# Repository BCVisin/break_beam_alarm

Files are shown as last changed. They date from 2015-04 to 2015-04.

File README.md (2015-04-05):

# Break Beam Alarm

A dual laser break beam sensor system. 

###Details

I needed to set up an alarm system on 2 doors that lead out to the pool area so we will be notified if our children walked outside.  I didn't like the door alarm systems like this http://amzn.com/B0046786U4 since they don't work on the sliding door and the screen door. I wanted a system that checked to see if anyone crossed the door threshold.  A break beam system was in order. I thought the Pi would be a great at this and it would be a fun little project.

I am using the following hardware:
 1. Raspberry Pi A+ - The brains http://amzn.com/B00PEX05TO
 2. Edimax EW-7811Un 150Mbps 11n Wi-Fi USB Adapter - To connect the Pi to the network http://amzn.com/B003MTTJOY
 3. Kingston Digital 8 GB microSDHC - The Pi's memory http://amzn.com/B004S1PNE0
 4. Anker 10000mAh Battery Power Bank - In case of power outage to keep the system running http://amzn.com/B009USAJCC
 5. 2x Laser Diode - LASERS (need I say more?) https://www.adafruit.com/products/1054
 6. 2x Photo Cel (CdS photoresistor) - To detect the light changes when the laser beam is broken, https://www.adafruit.com/products/161
 7. 3x Square Buttons - Tactile reset buttons https://www.adafruit.com/products/1010
 8. USB Powered Speakers - To play various alarm sounds https://www.adafruit.com/products/1363
 9. MCP3008 - 8-Channel 10-Bit ADC - http://www.adafruit.com/products/856
 10. Various resistors for LEDs and the photo cel

###Requirements

 - A laser sensor across 2 door frame
 - 2 bypass buttons located on the upper part of the wall by the door so the kids can't reach it
 - When either beam is broken for the first time, it sounds an alarm and turns on an LED
 - When either beam is broken again (before being reset) it sounds a second (different) alarm and truns on a different LED
 - When either bypass button is pushed it will silense and reset the alarms
 - When either bypass button is pushed it will give a grace period (5 seconds?) to pass through the beams without alarms being triggered
 - Ability to run neither, one or the other, or both laser sensors at any give time

###Images
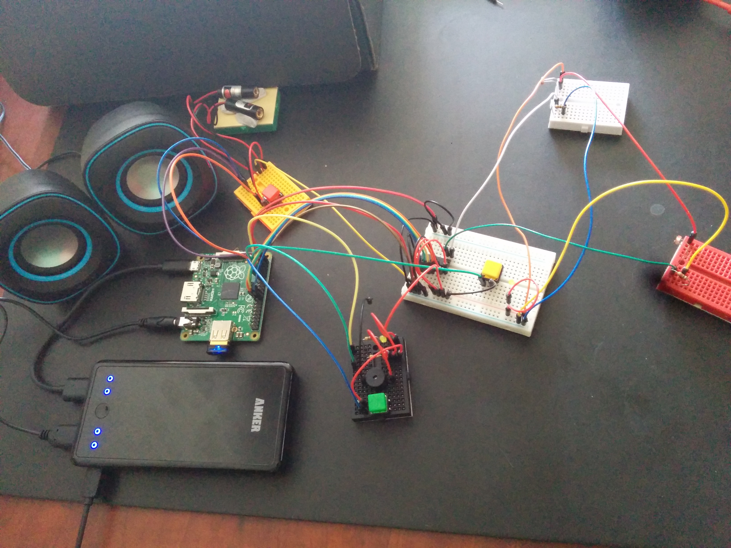
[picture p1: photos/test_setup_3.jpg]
Image of Test Setup

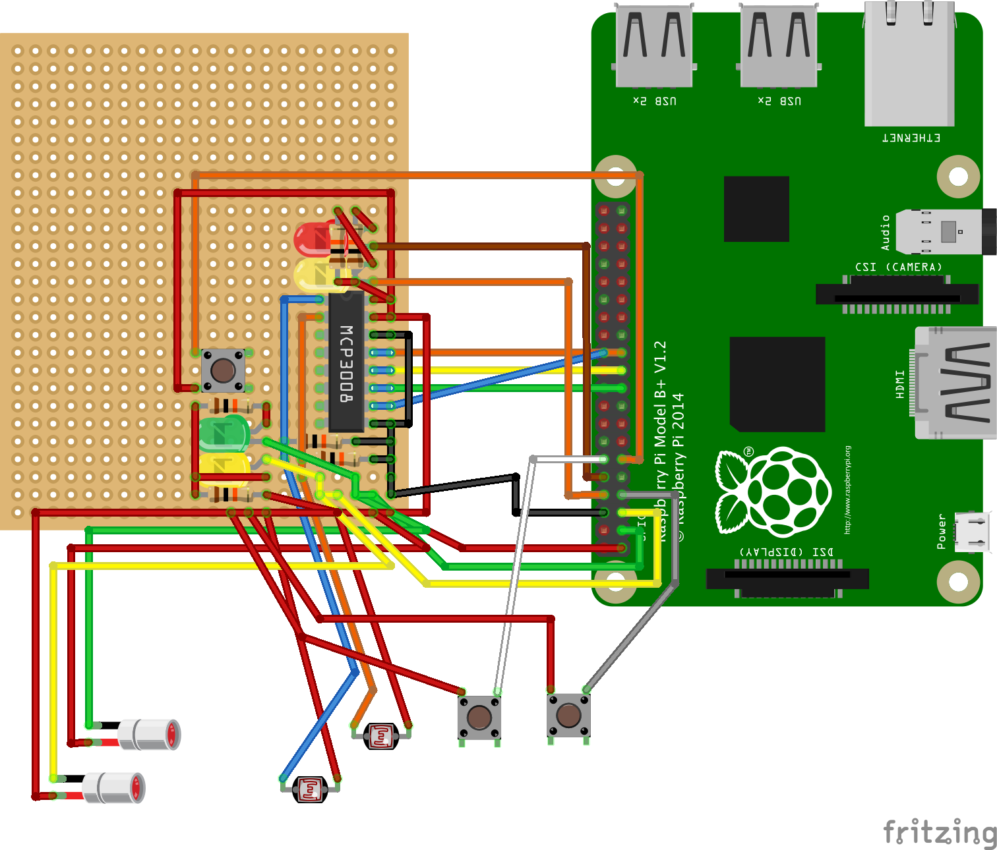
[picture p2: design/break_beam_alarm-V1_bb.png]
Image of Circuit


###Notes

The script MUST be ran as root since it needs access to the Pi's GPIO ports.

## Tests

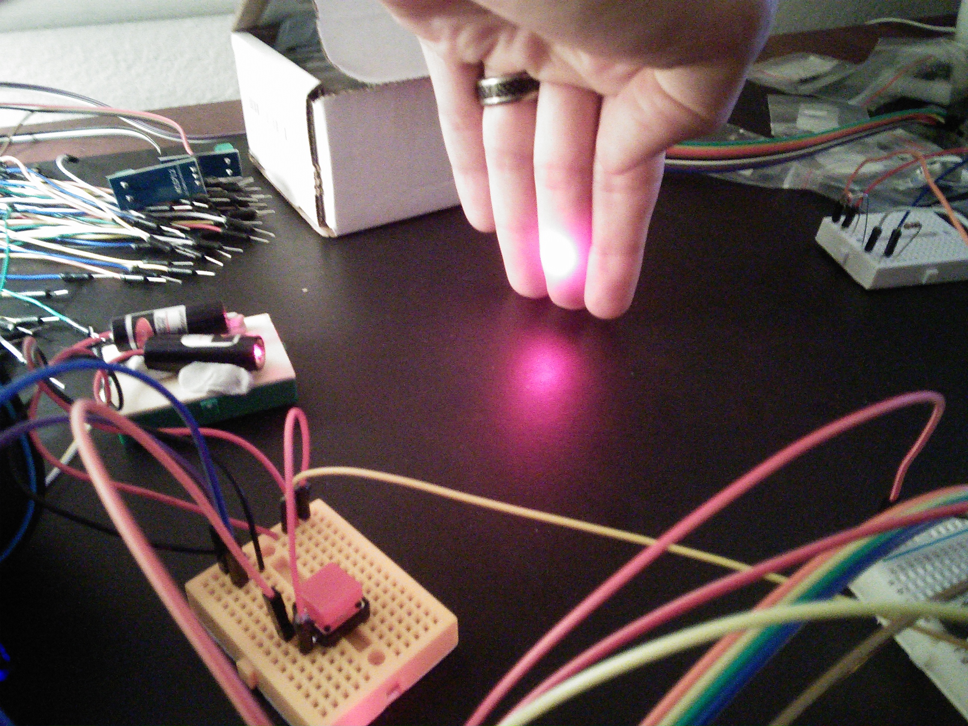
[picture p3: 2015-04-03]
photos/test_setup_2.jpg

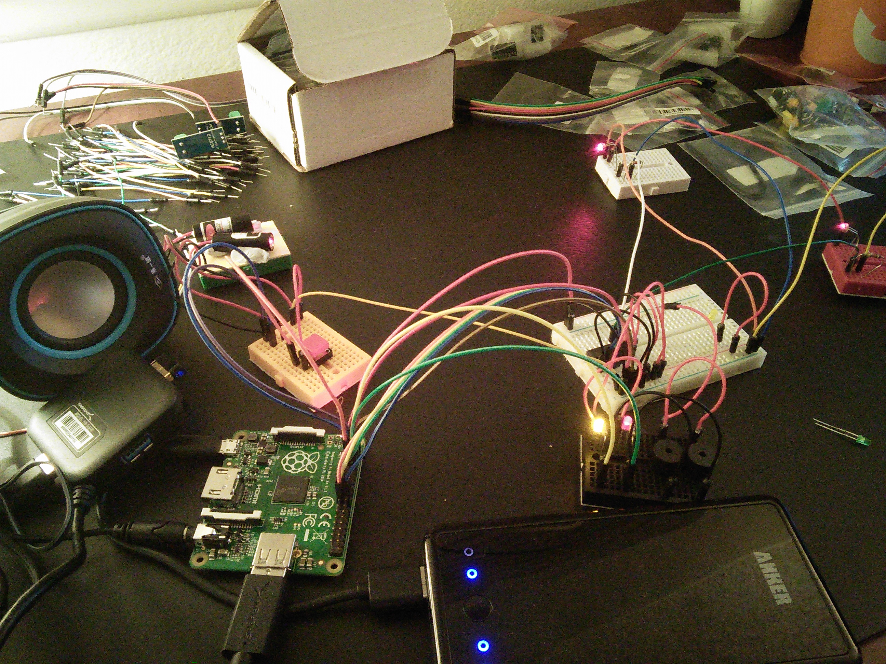
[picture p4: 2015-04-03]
photos/test_setup_1.jpg

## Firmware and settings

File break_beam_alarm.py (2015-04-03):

# -*- coding: utf-8 -*-
# <nbformat>3.0</nbformat>

# <codecell>

import os
import time
import datetime
import subprocess
import RPi.GPIO as GPIO

# <codecell>

#the counter to know how many times it has been tripped
TRIPPED = 0

#do we want to sound the alarms?
AUDIO = False

#The volume for the alarms in % (can be more than 100%)
VOLUME = '10'

#The MP3 files of the alarms (They will loop)
ALARM1_AUDIO_FILE = 'alarms/alarm1.mp3'
ALARM2_AUDIO_FILE = 'alarms/alarm2.mp3'

#set up some variables
PROCESS = None
BEGIN = datetime.datetime.now()

#how long should we wait till after the button is pressed to trigger an alarma again
BUTTON_GRACE_PERIOD = 5 #in seconds
#how long after an alarm is triggered should we wait to trigger the next alarm
BREAK_GRACE_PERIOD = 1 #in seconds

#Which doors do we want active (0 = none, 1 = Door 1, 2 = Door 2, 3 = All)
DOORS = 3

#setup the sensitivity threshold for the analog reading on the ADC chip
ANALOG_PIN0_SENSITIVITY = 900
ANALOG_PIN1_SENSITIVITY = 700
PATL = {0:ANALOG_PIN0_SENSITIVITY, 1:ANALOG_PIN1_SENSITIVITY}


# <codecell>

GPIO.setwarnings(False)

#Name and number the GPIO pins
SPICLK = 11
SPIMISO = 9
SPIMOSI = 10
SPICS = 8

LASER1 = 2
LASER2 = 3

BUTTON1 = 4
BUTTON2 = 18
ALARM1 = 14
ALARM2 = 15

TOGGLE = 17

GPIO.setmode(GPIO.BCM)

# set up the GPIO
GPIO.setup(SPIMOSI, GPIO.OUT)
GPIO.setup(SPIMISO, GPIO.IN)
GPIO.setup(SPICLK, GPIO.OUT)
GPIO.setup(SPICS, GPIO.OUT)


GPIO.setup(LASER1,GPIO.OUT, initial=GPIO.LOW)
GPIO.setup(LASER2,GPIO.OUT, initial=GPIO.LOW)

GPIO.setup(BUTTON1,GPIO.IN,pull_up_down=GPIO.PUD_DOWN)
GPIO.setup(BUTTON2,GPIO.IN,pull_up_down=GPIO.PUD_DOWN)

GPIO.setup(TOGGLE,GPIO.IN,pull_up_down=GPIO.PUD_DOWN)

GPIO.setup(ALARM1,GPIO.OUT, initial=GPIO.HIGH)
GPIO.setup(ALARM2,GPIO.OUT, initial=GPIO.HIGH)

# <codecell>

#the bit bangled implementation of the ADC chip
def readadc(adcnum, clockpin, mosipin, misopin, cspin):
        if ((adcnum > 7) or (adcnum < 0)):
                return -1
        GPIO.output(cspin, True)
 
        GPIO.output(clockpin, False) 
        GPIO.output(cspin, False)
 
        commandout = adcnum
        commandout |= 0x18
        commandout <<= 3
        for i in range(5):
                if (commandout & 0x80):
                        GPIO.output(mosipin, True)
                else:
                        GPIO.output(mosipin, False)
                commandout <<= 1
                GPIO.output(clockpin, True)
                GPIO.output(clockpin, False)
 
        adcout = 0
        for i in range(12):
                GPIO.output(clockpin, True)
                GPIO.output(clockpin, False)
                adcout <<= 1
                if (GPIO.input(misopin)):
                        adcout |= 0x1
 
        GPIO.output(cspin, True)
        
        adcout >>= 1
        return adcout

# <codecell>

#sense if the door has been tripped
def sense_trip(pins_and_trip_limit):
    
    #how many readings to take and average.  It takes about 2K reading as second
    average_count = 500
    
    patl = PATL
    
    #Block and wait till we sense it's tripped
    while True:
        #if we detect that the global PATL variable has changed, we don't want to block so we return false
        if PATL != patl:
            return False
        
        #set up the sum for the average
        light_sum = {x:0 for x in pins_and_trip_limit.keys()}
        #loop through to add it all up
        for i in range(0, average_count):
            for adc_pin in pins_and_trip_limit.keys():
                light_sum[adc_pin] += readadc(adc_pin, SPICLK, SPIMOSI, SPIMISO, SPICS)
        #loop through to check if we crossd the threshold
        for adc_pin, tripped_limit in pins_and_trip_limit.items():
            if (light_sum[adc_pin] / average_count) < tripped_limit:
                #if we have return True
                return True

# <codecell>

#if we press the clear button we want to do stuff
def button_clear(channel):
    
    global TRIPPED
    global PROCESS
    global BEGIN
    
    #if the sensor has been tripped reset the counter, clear the alarms, and kill the process
    if TRIPPED > 0:
        TRIPPED = 0
        GPIO.output(ALARM1, GPIO.HIGH)
        GPIO.output(ALARM2, GPIO.HIGH)
        if PROCESS:
            PROCESS.kill()
    #otherwise we just want to reset the timer so we have time to cross the beam without the alarm going off
    else:
       BEGIN = datetime.datetime.now() 
    

# <codecell>


def toggle_doors(channel):
    
    """This toggle switch changes between none, door one, door two, or both"""
    
    global DOORS
    global PATL
    global BEGIN
    
    #reset the time so we don't accidently set the alarm off when switching
    BEGIN = datetime.datetime.now()
    
    #increment the doors
    DOORS += 1
    if DOORS > 3:
        #if we have reached 3, reset it to 0
        DOORS = 0
    
    #sensors off
    if DOORS == 0:
        PATL = {}
        GPIO.output(LASER1,GPIO.HIGH)
        GPIO.output(LASER2,GPIO.HIGH)
    #single door on
    elif DOORS == 1:
        PATL = {0:ANALOG_PIN0_SENSITIVITY}
        GPIO.output(LASER1,GPIO.HIGH)
        GPIO.output(LASER2,GPIO.LOW)
    #single door off
    elif DOORS == 2:
        PATL = {1:ANALOG_PIN1_SENSITIVITY}
        GPIO.output(LASER1,GPIO.LOW)
        GPIO.output(LASER2,GPIO.HIGH)
    #both doors on
    elif DOORS == 3:
        PATL = {0:ANALOG_PIN0_SENSITIVITY, 1:ANALOG_PIN1_SENSITIVITY}
        GPIO.output(LASER1,GPIO.LOW)
        GPIO.output(LASER2,GPIO.LOW)

    

# <codecell>
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

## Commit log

2015-04-03 The first version of the script. This likely will be broken apart into classes and a configuration file as I expand on it
    [break_beam_alarm.py]
2015-04-05 added designs
    Added in the circuitry design using the Fritzing program -
    http://fritzing.org/
    [break_beam_alarm-V1.fzz]
